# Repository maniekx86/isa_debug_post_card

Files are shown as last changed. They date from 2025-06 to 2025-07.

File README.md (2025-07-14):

# ISA debug post card
ISA debug post card with additional features like data/address bus analyzer, frequency measure and multi I/O POST port selection. Uses a XC95144XL CPLD as main IC. Dedicated project page with manual and assembly instructions will be available soon.

It is also designed to have a 45-degree bevel at the connector. When ordering, enable edge connector and a 45-degree bevel. Ready gerbers are available in output folder

CPLD VHDL source code and compiled firmware for the CPLD are available here: https://github.com/maniekx86/isa_debug_post_card_cpld_source

Based on https://github.com/JayesonLS/ISA-Cards IsaTemplate

## Special thanks to [PCBWay](https://www.pcbway.com)!
[](https://www.pcbway.com)

Special thanks to PCBWay for sponsoring this project! PCBWay is a well-known PCB prototyping and manufacturing service, providing high-quality boards and excellent customer support. I have worked with their boards in the past and can say that they are of great quality. I easily placed an order for PCBs on their platform for this project without any problems. The sponsorship also included a free quick delivery option. If you’re looking for reliable PCB prototyping and manufacturing services, I highly recommend [checking them](https://www.pcbway.com).

## Photos
front
back

post_card_3drenders

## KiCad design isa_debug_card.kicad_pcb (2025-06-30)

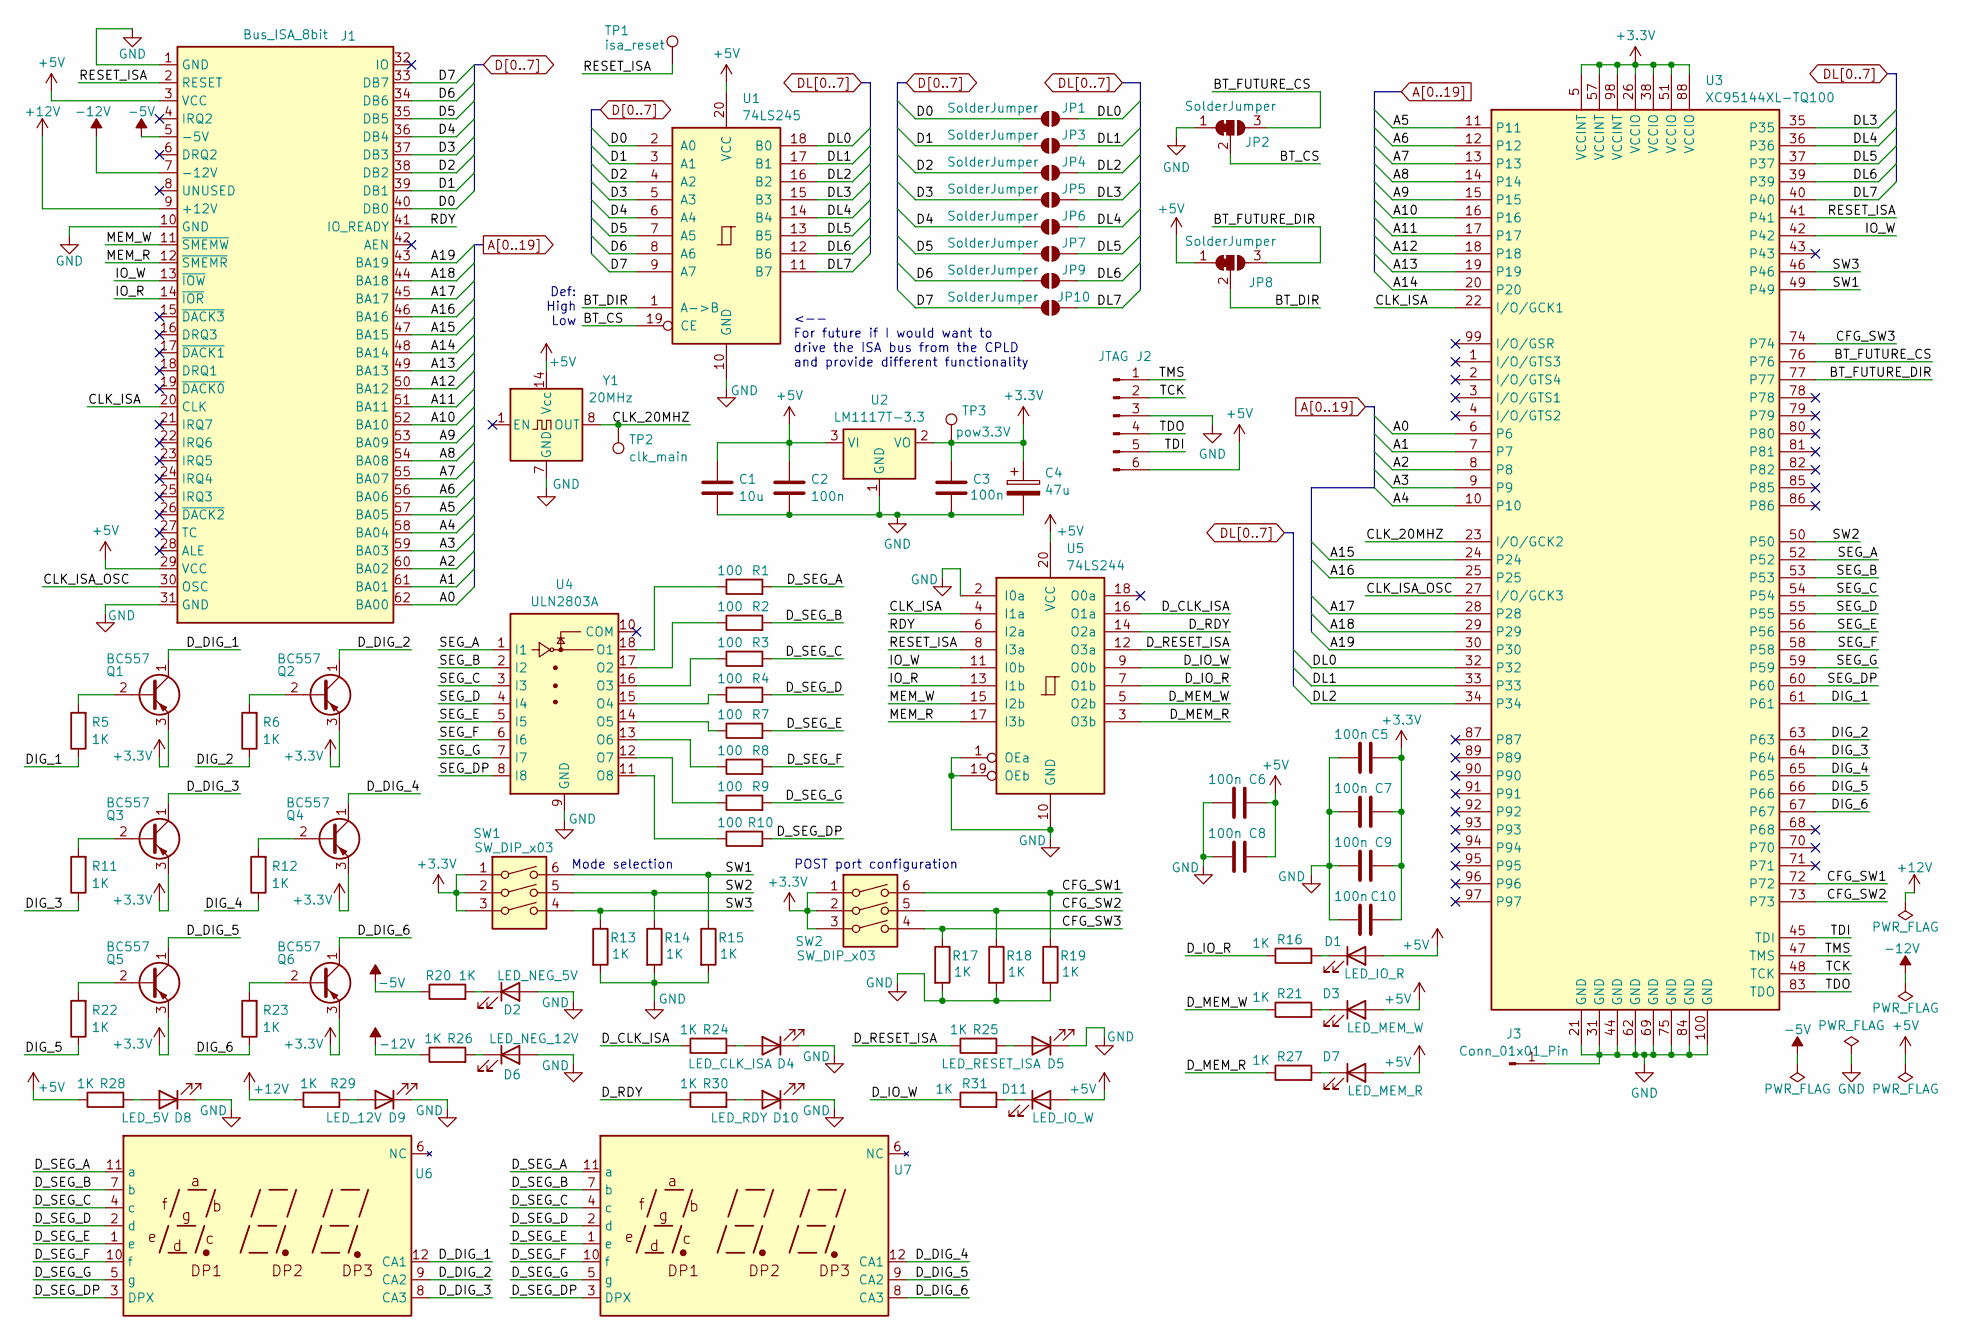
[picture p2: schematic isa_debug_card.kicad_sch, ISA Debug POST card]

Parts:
C1: 10u; CP_Radial_D5.0mm_P2.50mm
C2, C3, C5, C6, C7, C8, C9, C10: 100n; C_Disc_D3.0mm_W2.0mm_P2.50mm
C4: 47u; CP_Radial_D5.0mm_P2.50mm
D1: LED_IO_R; LED_D5.0mm
D2: LED_NEG_5V; LED_D5.0mm
D3: LED_MEM_W; LED_D5.0mm
D4: LED_CLK_ISA; LED_D5.0mm
D5: LED_RESET_ISA; LED_D5.0mm
D6: LED_NEG_12V; LED_D5.0mm
D7: LED_MEM_R; LED_D5.0mm
D8: LED_5V; LED_D5.0mm
D9: LED_12V; LED_D5.0mm
D10: LED_RDY; LED_D5.0mm
D11: LED_IO_W; LED_D5.0mm
J1: Bus_ISA_8bit; BUS_XT
J2: JTAG; PinSocket_1x06_P2.54mm_Vertical
J3: Conn_01x01_Pin; PinHeader_1x01_P2.54mm_Vertical
JP1, JP3, JP4, JP5, JP6, JP7, JP9, JP10: SolderJumper; SolderJumper-2_P1.3mm_Open_Pad1.0x1.5mm
JP2, JP8: SolderJumper; SolderJumper-3_P1.3mm_Bridged12_Pad1.0x1.5mm
Q1, Q2, Q3, Q4, Q5, Q6: BC557; TO-92_Inline
R1, R2, R3, R4, R7, R8, R9, R10: 100; R_Axial_DIN0204_L3.6mm_D1.6mm_P7.62mm_Horizontal
R5, R6, R11, R12, R13, R14, R15, R16, R17, R18, R19, R20, R21, R22, R23, R24, R25, R26, R27, R28, R29, R30, R31: 1K; R_Axial_DIN0204_L3.6mm_D1.6mm_P7.62mm_Horizontal
SW1, SW2: SW_DIP_x03; SW_DIP_SPSTx03_Slide_9.78x9.8mm_W7.62mm_P2.54mm
TP1: isa_reset; TestPoint_Pad_2.0x2.0mm
TP2: clk_main; TestPoint_Pad_2.0x2.0mm
TP3: pow3.3V; TestPoint_Pad_2.0x2.0mm
U1: 74LS245; DIP-20_W7.62mm
U2: LM1117T-3.3; TO-220-3_Horizontal_TabDown
U3: XC95144XL-TQ100; TQFP-100_14x14mm_P0.5mm
U4: ULN2803A; DIP-18_W7.62mm
U5: 74LS244; DIP-20_W7.62mm
U6, U7: LED_3_digit_0_56inch_12pin
Y1: 20MHz; OSC_8_14_Multi

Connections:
+3.3V: C3.1, C4.1, C5.2, C7.2, C9.2, C10.2, Q1.3 (E), Q2.3 (E), Q3.3 (E), Q4.3 (E), Q5.3 (E), Q6.3 (E), SW1.1, SW1.2, SW1.3, SW2.1, SW2.2, SW2.3, TP3.1, U2.2 (VO), U3.5 (VCCINT), U3.26 (VCCIO), U3.38 (VCCIO), U3.51 (VCCIO), U3.57 (VCCINT), U3.88 (VCCIO), U3.98 (VCCINT)
+5V: C1.1, C2.1, C6.2, C8.2, D1.2 (A), D3.2 (A), D7.2 (A), D11.2 (A), J1.3 (VCC), J1.29 (VCC), J2.6, JP8.1 (A), R28.1, U1.20 (VCC), U2.3 (VI), U5.20 (VCC), Y1.14 (Vcc)
+12V: J1.9 (+12V), R29.1
-5V: J1.5 (-5V), R20.1
-12V: J1.7 (-12V), R26.1
/BT_CS: JP2.2 (C), U1.19 (CE)
/BT_DIR: JP8.2 (C), U1.1 (A->B)
/BT_FUTURE_CS: JP2.3 (B), U3.76
/BT_FUTURE_DIR: JP8.3 (B), U3.77
/CFG_SW1: R19.1, SW2.6, U3.72
/CFG_SW2: R18.1, SW2.5, U3.73
/CFG_SW3: R17.1, SW2.4, U3.74
/CLK_20MHZ: TP2.1, U3.23 (I/O/GCK2), Y1.8 (OUT)
/CLK_ISA: J1.20 (CLK), U3.22 (I/O/GCK1), U5.4 (I1a)
/CLK_ISA_OSC: J1.30 (OSC), U3.27 (I/O/GCK3)
/DIG_1: R5.1, U3.61
/DIG_2: R6.1, U3.63
/DIG_3: R11.1, U3.64
/DIG_4: R12.1, U3.65
/DIG_5: R22.1, U3.66
/DIG_6: R23.1, U3.67
/D_CLK_ISA: R24.1, U5.16 (O1a)
/D_DIG_1: Q1.1 (C), U6.12 (CA1)
/D_DIG_2: Q2.1 (C), U6.9 (CA2)
/D_DIG_3: Q3.1 (C), U6.8 (CA3)
/D_DIG_4: Q4.1 (C), U7.12 (CA1)
/D_DIG_5: Q5.1 (C), U7.9 (CA2)
/D_DIG_6: Q6.1 (C), U7.8 (CA3)
/D_IO_R: R16.1, U5.7 (O1b)
/D_IO_W: R31.1, U5.9 (O0b)
/D_MEM_R: R27.1, U5.3 (O3b)
/D_MEM_W: R21.1, U5.5 (O2b)
/D_RDY: R30.1, U5.14 (O2a)
/D_RESET_ISA: R25.1, U5.12 (O3a)
/D_SEG_A: R1.2, U6.11 (a), U7.11 (a)
/D_SEG_B: R2.2, U6.7 (b), U7.7 (b)
/D_SEG_C: R3.2, U6.4 (c), U7.4 (c)
/D_SEG_D: R4.2, U6.2 (d), U7.2 (d)
/D_SEG_DP: R10.2, U6.3 (DPX), U7.3 (DPX)
/D_SEG_E: R7.2, U6.1 (e), U7.1 (e)
/D_SEG_F: R8.2, U6.10 (f), U7.10 (f)
/D_SEG_G: R9.2, U6.5 (g), U7.5 (g)
/IO_R: J1.14 (~IOR), U5.13 (I1b)
/IO_W: J1.13 (~IOW), U3.42, U5.11 (I0b)
/MEM_R: J1.12 (~SMEMR), U5.17 (I3b)
/MEM_W: J1.11 (~SMEMW), U5.15 (I2b)
/RDY: J1.41 (IO_READY), U5.6 (I2a)
/RESET_ISA: J1.2 (RESET), TP1.1, U3.41, U5.8 (I3a)
/SEG_A: U3.52, U4.1 (I1)
/SEG_B: U3.53, U4.2 (I2)
/SEG_C: U3.54, U4.3 (I3)
/SEG_D: U3.55, U4.4 (I4)
/SEG_DP: U3.60, U4.8 (I8)
/SEG_E: U3.56, U4.5 (I5)
/SEG_F: U3.58, U4.6 (I6)
/SEG_G: U3.59, U4.7 (I7)
/SW1: R15.1, SW1.6, U3.49
/SW2: R14.1, SW1.5, U3.50
/SW3: R13.1, SW1.4, U3.46
/TCK: J2.2, U3.48 (TCK)
/TDI: J2.5, U3.45 (TDI)
/TDO: J2.4, U3.83 (TDO)
/TMS: J2.1, U3.47 (TMS)
A0: J1.62 (BA00), U3.6
A1: J1.61 (BA01), U3.7
A2: J1.60 (BA02), U3.8
A3: J1.59 (BA03), U3.9
A4: J1.58 (BA04), U3.10
A5: J1.57 (BA05), U3.11
A6: J1.56 (BA06), U3.12
A7: J1.55 (BA07), U3.13
A8: J1.54 (BA08), U3.14
A9: J1.53 (BA09), U3.15
A10: J1.52 (BA10), U3.16
A11: J1.51 (BA11), U3.17
A12: J1.50 (BA12), U3.18
A13: J1.49 (BA13), U3.19
A14: J1.48 (BA14), U3.20
A15: J1.47 (BA15), U3.24
A16: J1.46 (BA16), U3.25
A17: J1.45 (BA17), U3.28
A18: J1.44 (BA18), U3.29
A19: J1.43 (BA19), U3.30
D0: J1.40 (DB0), JP1.1 (A), U1.2 (A0)
D1: J1.39 (DB1), JP3.1 (A), U1.3 (A1)
D2: J1.38 (DB2), JP4.1 (A), U1.4 (A2)
D3: J1.37 (DB3), JP5.1 (A), U1.5 (A3)
D4: J1.36 (DB4), JP6.1 (A), U1.6 (A4)
D5: J1.35 (DB5), JP7.1 (A), U1.7 (A5)
D6: J1.34 (DB6), JP9.1 (A), U1.8 (A6)
D7: J1.33 (DB7), JP10.1 (A), U1.9 (A7)
DL0: JP1.2 (B), U1.18 (B0), U3.32
DL1: JP3.2 (B), U1.17 (B1), U3.33
DL2: JP4.2 (B), U1.16 (B2), U3.34
DL3: JP5.2 (B), U1.15 (B3), U3.35
DL4: JP6.2 (B), U1.14 (B4), U3.36
DL5: JP7.2 (B), U1.13 (B5), U3.37
DL6: JP9.2 (B), U1.12 (B6), U3.39
DL7: JP10.2 (B), U1.11 (B7), U3.40
GND: C1.2, C2.2, C3.2, C4.2, C5.1, C6.1, C7.1, C8.1, C9.1, C10.1, D2.2 (A), D4.1 (K), D5.1 (K), D6.2 (A), D8.1 (K), D9.1 (K), D10.1 (K), J1.1 (GND), J1.10 (GND), J1.31 (GND), J2.3, J3.1, JP2.1 (A), R13.2, R14.2, R15.2, R17.2, R18.2, R19.2, U1.10 (GND), U2.1 (GND), U3.21 (GND), U3.31 (GND), U3.44 (GND), U3.62 (GND), U3.69 (GND), U3.75 (GND), U3.84 (GND), U3.100 (GND), U4.9 (GND), U5.1 (OEa), U5.2 (I0a), U5.10 (GND), U5.19 (OEb), Y1.7 (GND)
unnamed: D1.1 (K), R16.2
unnamed: D2.1 (K), R20.2
unnamed: D3.1 (K), R21.2
unnamed: D4.2 (A), R24.2
unnamed: D5.2 (A), R25.2
unnamed: D6.1 (K), R26.2
unnamed: D7.1 (K), R27.2
unnamed: D8.2 (A), R28.2
unnamed: D9.2 (A), R29.2
unnamed: D10.2 (A), R30.2
unnamed: D11.1 (K), R31.2
unnamed: Q1.2 (B), R5.2
unnamed: Q2.2 (B), R6.2
unnamed: Q3.2 (B), R11.2
unnamed: Q4.2 (B), R12.2
unnamed: Q5.2 (B), R22.2
unnamed: Q6.2 (B), R23.2
unnamed: R1.1, U4.18 (O1)
unnamed: R2.1, U4.17 (O2)
unnamed: R3.1, U4.16 (O3)
unnamed: R4.1, U4.15 (O4)
unnamed: R7.1, U4.14 (O5)
unnamed: R8.1, U4.13 (O6)
unnamed: R9.1, U4.12 (O7)
unnamed: R10.1, U4.11 (O8)

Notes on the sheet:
Def: High Low
<-- For future if I would want to drive the ISA bus from the CPLD and provide different functionality
Mode selection
POST port configuration

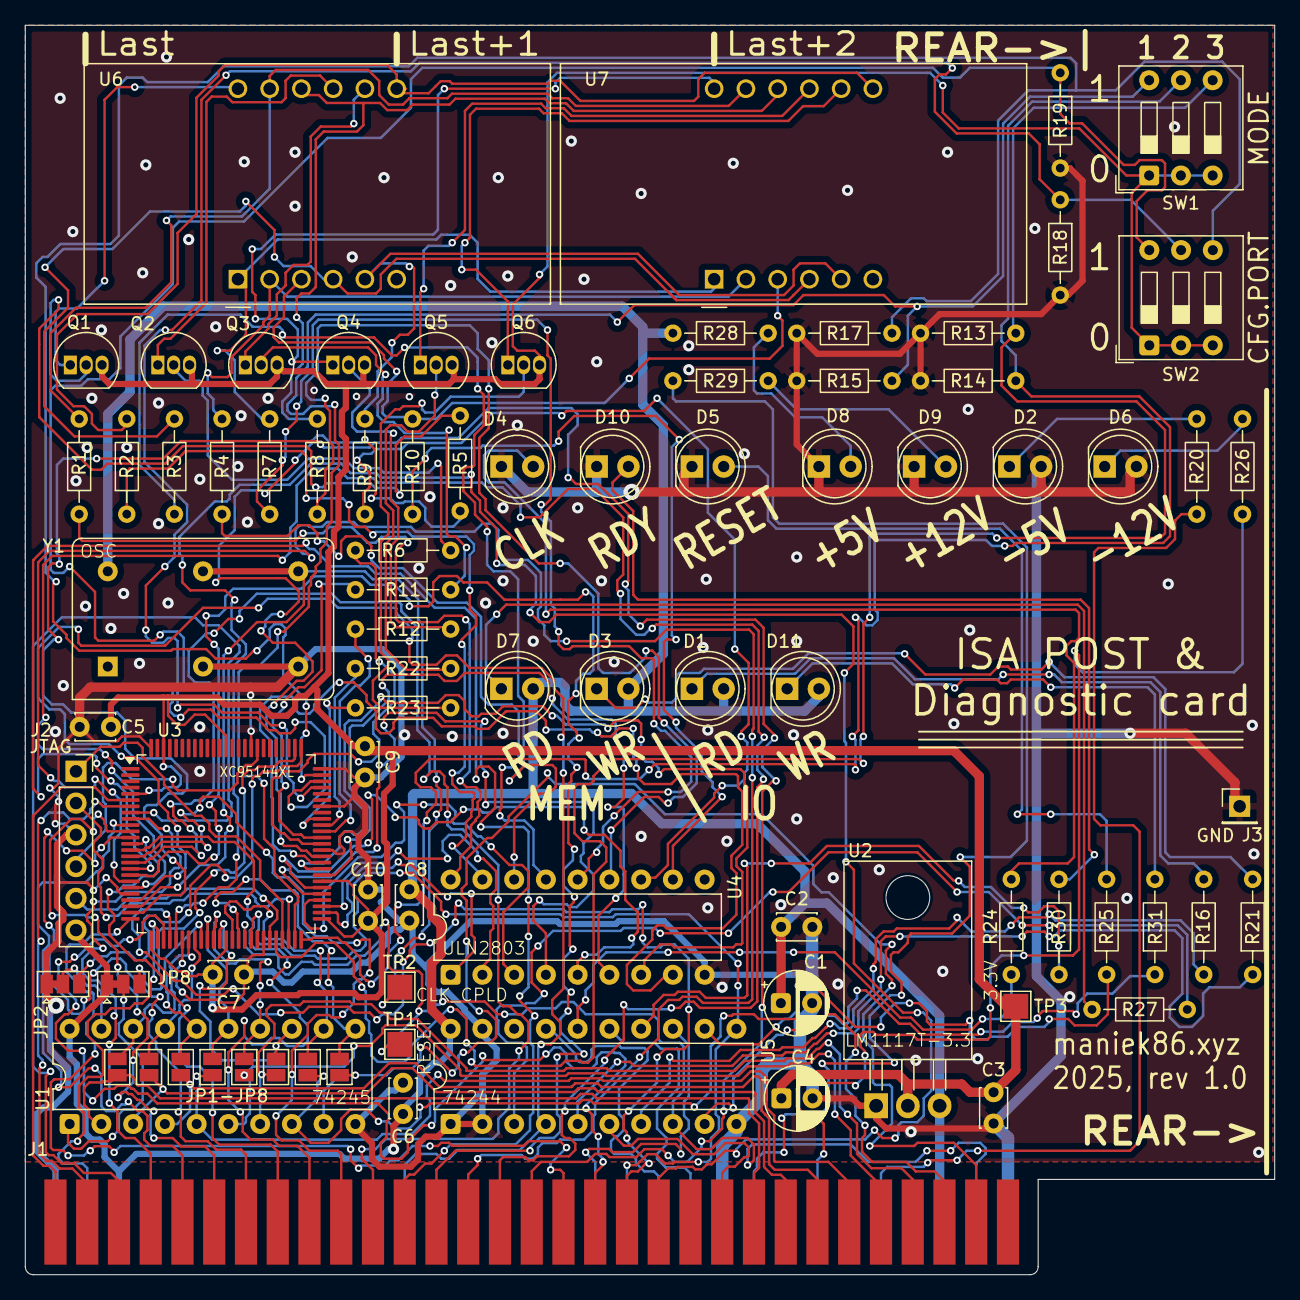
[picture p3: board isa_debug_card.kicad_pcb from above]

Board: 2 copper layers, 99.9 x 99.9 mm, 84 parts (0 on the bottom side), 125 nets.

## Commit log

2025-06-30 Add KiCad files
    [isa_debug_card-B_Cu.gbr, isa_debug_card-B_Mask.gbr, isa_debug_card-B_Paste.gbr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]
2025-07-08 Update README.md (Thanks to PCBWay!)
